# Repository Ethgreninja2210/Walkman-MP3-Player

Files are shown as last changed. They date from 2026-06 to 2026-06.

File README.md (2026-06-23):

# Walkman-MP3-Player
I frequently do revision to some background music that both blocks out the background noise but is also not too distracting which usually I use a Spotify playlist but lots of the time going onto this playlist or skipping a song leads to me scrolling on my phone and at that point I’ve lost focus and will probably end up on Instagram. This should solve this issue by basically being a brick that ONLY plays my revision music, it will also use wired headphones so that if my Bluetooth headphones are dead, I still have this music so again, I am less likely to procrastinate my revision. 

The created device is a reasonably nice looking rendition of the popular sony walkman but instead plays whatever MP3 files are loaded onto the SD card. 

To create the product, Print the files from the reposetory and source the components from the BOM. Then wire all these in acordance to the wiring diagram bellow and assemble. For easier assembly, insert the keyboard switches and potentiometer before soldering and then solder these first. 

To set up the product after making it. Flash the firmware to the arduino NANO and wire all components to their respective ports. Rename the music MP3 files to sequentually increasing numbers from 0001, 0002, etc and copy these onto the SD card. insert the SD card into the DFPlayerMini module and seal the case. Optionally you can illustrait the different side buttons with symbols. Then the device is ready, switch it on, plug in headphones and start listening. 



## BOM

#### (For full BOM with links see the folder)
Quantity,  Item Name,

1,  DFPlayerMini,

1,  Arduino NANO,

1,  "0.91"" OLED Display",

1,  Potentiometer Dial,

1,  Toggle switch,£1.72,

4,  Mechanical Keyboard switches,

1,  TP4056 module,

1,  Battery - 3.7V,

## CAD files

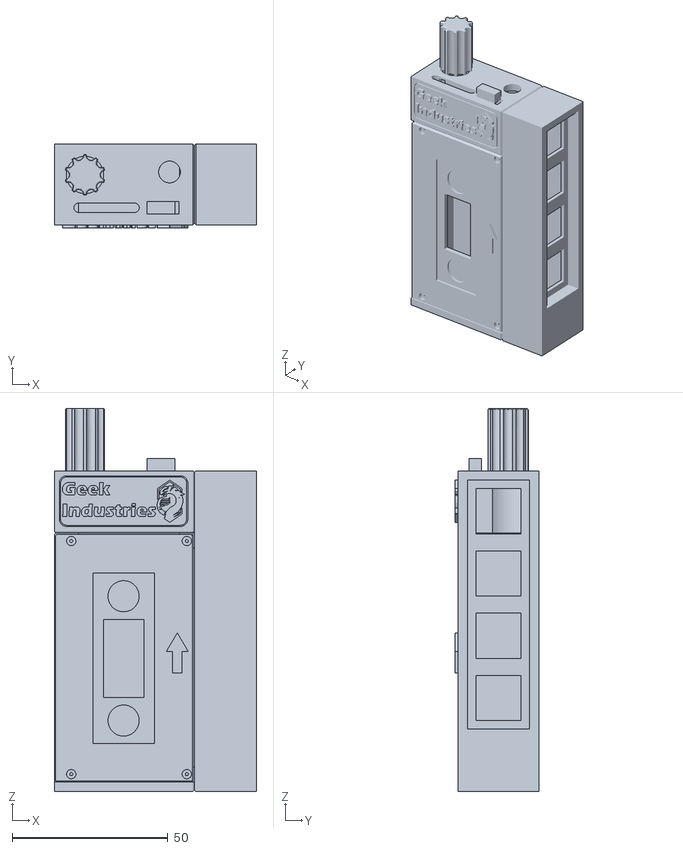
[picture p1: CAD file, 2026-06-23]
CAD/Walkman mp3.stl
65.0 x 27.0 x 123.0

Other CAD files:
CAD/.f3d/Case Side panel.f3d
CAD/.f3d/Case Top.f3d
CAD/.f3d/Dial.f3d
CAD/.f3d/Front Panel.f3d
CAD/.f3d/Main Case.f3d
CAD/.f3d/Plaque.f3d
CAD/.f3d/Switch.f3d

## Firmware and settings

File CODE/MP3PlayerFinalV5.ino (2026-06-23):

#include <Arduino.h>
#include <SoftwareSerial.h>
#include <DFRobotDFPlayerMini.h>
#include <U8g2lib.h>
#include <Wire.h>
#include <EEPROM.h>
#include "OneButton.h"

// Icon fonts: U8g2's built-in, verified "Open Iconic" icon sets.
// (A custom font was tried earlier but its binary data gets corrupted by any
// text-based copy/paste, so these official library fonts are used instead —
// no extra files needed, just U8g2 library version ≥2.22.)
//   u8g2_font_open_iconic_play_2x_t -> play(69) pause(68) skip-back(71) skip-fwd(72)

// ── Pin definitions ──────────────────────────────────────────────────────────
const uint8_t leftButtonPin      = 2;   // Previous track (direct skip)
const uint8_t selectionButtonPin = 5;   // Play / Pause
const uint8_t rightButtonPin     = 8;   // Next track (direct skip)
const uint8_t eqButtonPin        = 9;   // Cycle EQ preset
const uint8_t potPin             = A0;  // Potentiometer for volume

// ── State variables ──────────────────────────────────────────────────────────
volatile bool updateScreen = true;

uint8_t filecounts;
uint8_t volume = 20;
uint8_t file   = 1;
uint8_t eq     = 0;

// Potentiometer smoothing
int     lastPotValue   = -1;
uint8_t lastVolumeSent  = 255;   // force a send on first read

boolean playing = false;

OneButton PreviousBTN(leftButtonPin,      true);
OneButton PlayBTN    (selectionButtonPin, true);
OneButton NextBTN    (rightButtonPin,     true);
OneButton EqBTN      (eqButtonPin,        true);

// SoftwareSerial(RX, TX) — D12 carries data FROM the DFPlayer's TX pin (so D12
// is the Nano's RX), and D13 carries data TO the DFPlayer's RX pin (so D13 is
// the Nano's TX) — matches the wiring diagram.
SoftwareSerial customSoftwareSerial(12, 13);
DFRobotDFPlayerMini myDFPlayer;

U8G2_SH1106_128X64_NONAME_1_HW_I2C u8g2(U8G2_R0, U8X8_PIN_NONE);

// ── Boot animation ────────────────────────────────────────────────────────────
const uint8_t  STARTUP_MAX_BLOCKS = 40;
const uint8_t  STARTUP_BLOCK_SIZE = 10;
const uint16_t STARTUP_FRAME_MS   = 40;

uint8_t blockX[STARTUP_MAX_BLOCKS];
uint8_t blockY[STARTUP_MAX_BLOCKS];

void bootAnimation() {
  uint8_t blocksSoFar = 0;

  for (uint8_t frame = 0; frame <= STARTUP_MAX_BLOCKS; frame++) {
    if (frame < STARTUP_MAX_BLOCKS) {
      blockX[blocksSoFar] = random(0, u8g2.getDisplayWidth()  - STARTUP_BLOCK_SIZE);
      blockY[blocksSoFar] = random(0, u8g2.getDisplayHeight() - STARTUP_BLOCK_SIZE);
      blocksSoFar++;
    }

    u8g2.firstPage();
    do {
      if (frame < STARTUP_MAX_BLOCKS) {
        for (uint8_t i = 0; i < blocksSoFar; i++) {
          u8g2.drawBox(blockX[i], blockY[i], STARTUP_BLOCK_SIZE, STARTUP_BLOCK_SIZE);
        }
      }
    } while (u8g2.nextPage());

    delay(STARTUP_FRAME_MS);
  }
}

// ── Setup ────────────────────────────────────────────────────────────────────
void setup(void) {
  Serial.begin(9600);
  randomSeed(analogRead(A7));   // unused pin, just for boot-animation entropy
  u8g2.begin();
  bootAnimation();

  PreviousBTN.attachClick(previousButtonClicked);
  PlayBTN    .attachClick(playButtonClicked);
  NextBTN    .attachClick(nextButtonClicked);
  EqBTN      .attachClick(eqButtonClicked);

  PreviousBTN.setDebounceMs(50);
  PlayBTN    .setDebounceMs(50);
  NextBTN    .setDebounceMs(50);
  EqBTN      .setDebounceMs(50);

  customSoftwareSerial.begin(9600);
  if (!myDFPlayer.begin(customSoftwareSerial)) {
    Serial.println(F("Please insert the SD card!"));
  }

  // Restore EQ and last-played file from EEPROM (volume is hardware-controlled)
  eq   = EEPROM.read(1);  if (eq   > 5)   eq   = 5;
  file = EEPROM.read(2);  if (file >= 19) file = 1;

  delay(1000);

  // Read potentiometer immediately 
  volume = map(analogRead(potPin), 0, 1023, 0, 30);
  myDFPlayer.volume(volume);
  lastVolumeSent = volume;

  delay(500);
  startInitialPlay();
}

// ── Main loop ────────────────────────────────────────────────────────────────
void loop() {
  PreviousBTN.tick();
  PlayBTN    .tick();
  NextBTN    .tick();
  EqBTN      .tick();

  updateVolume();
  updateDisplay();
  updateDFplayer();
}

// ── Potentiometer volume ─────────────────────────────────────────────────────
// Only sends a new volume command when the pot moves enough to change the
// 0-30 DFPlayer volume level, so the serial line isn't flooded.
void updateVolume() {
  int raw = analogRead(potPin);
  if (abs(raw - lastPotValue) >= 4) {
    lastPotValue = raw;
    uint8_t newVol = (uint8_t) map(raw, 0, 1023, 0, 30);
    if (newVol != lastVolumeSent) {
      volume         = newVol;
      lastVolumeSent = newVol;
      myDFPlayer.volume(volume);
      updateScreen = true;   // refresh the volume bar
    }
  }
}

// ── Button callbacks ─────────────────────────────────────────────────────────
void previousButtonClicked() {
  myDFPlayer.previous();
  file--;
  playing = true;
  EEPROM.write(2, file);
  updateScreen = true;
}

void nextButtonClicked() {
  file++;
  myDFPlayer.next();
  playing = true;
  EEPROM.write(2, file);
  updateScreen = true;
}

void playButtonClicked() {
  if (playing) myDFPlayer.pause();
  else         myDFPlayer.start();
  playing = !playing;
  updateScreen = true;
}

// 4th button cycles through EQ presets (Normal/Pop/Rock/Jazz/Classic/Bass).
void eqButtonClicked() {
  eq = (eq + 1) % 6;
  myDFPlayer.EQ(eq);
  EEPROM.write(1, eq);
  updateScreen = true;
}

// ── DFPlayer helpers ─────────────────────────────────────────────────────────
void startInitialPlay() {
  filecounts = myDFPlayer.readFileCounts();
  myDFPlayer.play(file);
  playing = false;
}

void updateDFplayer() {
  if (myDFPlayer.available()) {
    uint8_t type  = myDFPlayer.readType();
    int     value = myDFPlayer.read();
    if (type == DFPlayerPlayFinished) {
      if (file < filecounts) {
        file++;
        myDFPlayer.play(file);
        EEPROM.write(2, file);
        updateScreen = true;
      }
    }
  }
}

// EQ preset single-letter label (top-right indicator)
char eqLetter(uint8_t e) {
  switch (e) {
    case 0: return 'N';   // Normal
    case 1: return 'P';   // Pop
    case 2: return 'R';   // Rock
    case 3: return 'J';   // Jazz
    case 4: return 'C';   // Classic
    case 5: return 'B';   // Bass
    default: return '?';
  }
}

// ── Display update ────────────────────────────────────────────────────────────
void updateDisplay() {
  if (updateScreen) {
    u8g2.firstPage();
    do {
      player();
      updateScreen = false;
    } while (u8g2.nextPage());
  }
}

// ── Volume bar (left edge, visual only) ──────────────────────────────────────
// potentiometer's current 0-30 mapped level.
void volumeBar() {
  const u8g2_uint_t barX      = 3;
  const u8g2_uint_t barY      = 4;
  const u8g2_uint_t barW      = 10;
  const u8g2_uint_t barH      = 56;     // total track height
  const u8g2_uint_t barBottom = barY + barH;

  // Outline
  u8g2.drawFrame(barX, barY, barW, barH);

  // Fill proportional to volume (0-30)
  u8g2_uint_t fillH = (u8g2_uint_t)((uint32_t)barH * volume / 30);
  if (fillH > barH - 2) fillH = barH - 2;   // keep inside the outline
  if (fillH > 0) {
    u8g2.drawBox(barX + 1, barBottom - 1 - fillH, barW - 2, fillH);
  }

  u8g2.drawVLine(barX + barW + 4, 0, 64);   // divider between bar and main UI
}

// ── EQ indicator (top-right) ─────────────────────────────────────────────────
void eqIndicator() {
  u8g2.setFont(u8g2_font_logisoso16_tf);
  char letter[2] = { eqLetter(eq), '\0' };
  u8g2.setCursor(112, 16);
  u8g2.print(letter);
}

// ── Player screen (single screen, no settings page) ──────────────────────────
void player() {
  volumeBar();
  eqIndicator();

  u8g2_uint_t midOriginX = 70, midOriginY = 44;

  // Track info, centred over the button row
  u8g2.setFontMode(0);
  u8g2.setFont(u8g2_font_glasstown_nbp_tf);
  char trackStr[12];
  snprintf(trackStr, sizeof(trackStr), "%d/%d", file, filecounts);
  uint8_t strWidth = u8g2.getStrWidth(trackStr);
  u8g2.setCursor(midOriginX - (strWidth / 2), 25);
  u8g2.print(trackStr);

  // Previous (skip-backward)
  u8g2.setFont(u8g2_font_open_iconic_play_2x_t);
  u8g2.drawGlyph(midOriginX - 32, midOriginY + 8, 71);

  // Play / Pause — centred between prev and next
  if (playing) u8g2.drawGlyph(midOriginX - 8, midOriginY + 8, 68);   // pause
  else         u8g2.drawGlyph(midOriginX - 8, midOriginY + 8, 69);   // play

  // Next (skip-forward)
  u8g2.drawGlyph(midOriginX + 16, midOriginY + 8, 72);
}

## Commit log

2026-06-23 Create BOM - MP3 Player
2026-06-23 Update print statement from 'Hello' to 'Goodbye'
2026-06-23 Update fmt.Println message from 'Hello' to 'Goodbye'
2026-06-23 Create Main Case
2026-06-23 Create Switch
